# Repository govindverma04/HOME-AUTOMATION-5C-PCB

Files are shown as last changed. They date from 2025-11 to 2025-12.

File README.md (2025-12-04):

# HOME-AUTOMATION-5C-PCB

# Smart Home Automation PCB

This is an open-source ESP32-based smart home automation PCB designed by me.  
It includes zero-cross detection, triac dimming, relay control and support for Alexa/Google integration (optional).

---

## 🚀 Features
- ESP32-based main controller  
- 4N25 Zero-Cross Detection  
- Triac-based AC dimming  
- Relay output for AC load ON/OFF  
- Indicator LEDs  
- Safe opto-isolated design  
- Can be used for fan dimming & bulb control  

---

## 🧰 Files in this Repository
- `schematics/` → Circuit diagram  
- `pcb/` → PCB design files  
- `firmware/` → ESP32 code  
- `bom/` → Part list of components  
- `images/` → PCB photos & renders  

---

## 🔧 How to Use / Instructions

### 1) Assemble the PCB
- Solder all resistors  
- Solder optocouplers (4N25, MOC3021, etc)  
- Solder triac (BT136 or chosen model)  
- Mount terminal blocks  
- Insert ESP32  

### 2) Power Requirements
- 5V input via Hi-Link / External SMPS  
- ESP32 runs at 3.3V (regulator included)

### 3) Upload the Firmware
1. Download code from `firmware/` folder  
2. Open in Arduino IDE or PlatformIO  
3. Select board → ESP32 Dev Module  
4. Upload code  
5. Open Serial Monitor → you should see boot messages  

### 4) Connecting AC Load (⚠️ Safety First!)
- Only connect AC when you are confident  
- Use proper insulation  
- Fan/Bulb should connect through triac output  
- Relay output supports ON/OFF loads  

---

## 🧪 Testing
- Connect a test load or bulb  
- Verify Zero-Cross is detected (LED should blink)  
- Check dimming using serial or app  
- Test safety circuits  

---

## 🤝 Contributing
If you want to improve this project:
- Open an issue  
- Submit a pull request  
- Suggest new features  

---

## 📜 License
This project is open-source under the MIT License.

---

## 📞 Contact
Maintainer: **Govind**  
GitHub: https://github.com/govindverma04

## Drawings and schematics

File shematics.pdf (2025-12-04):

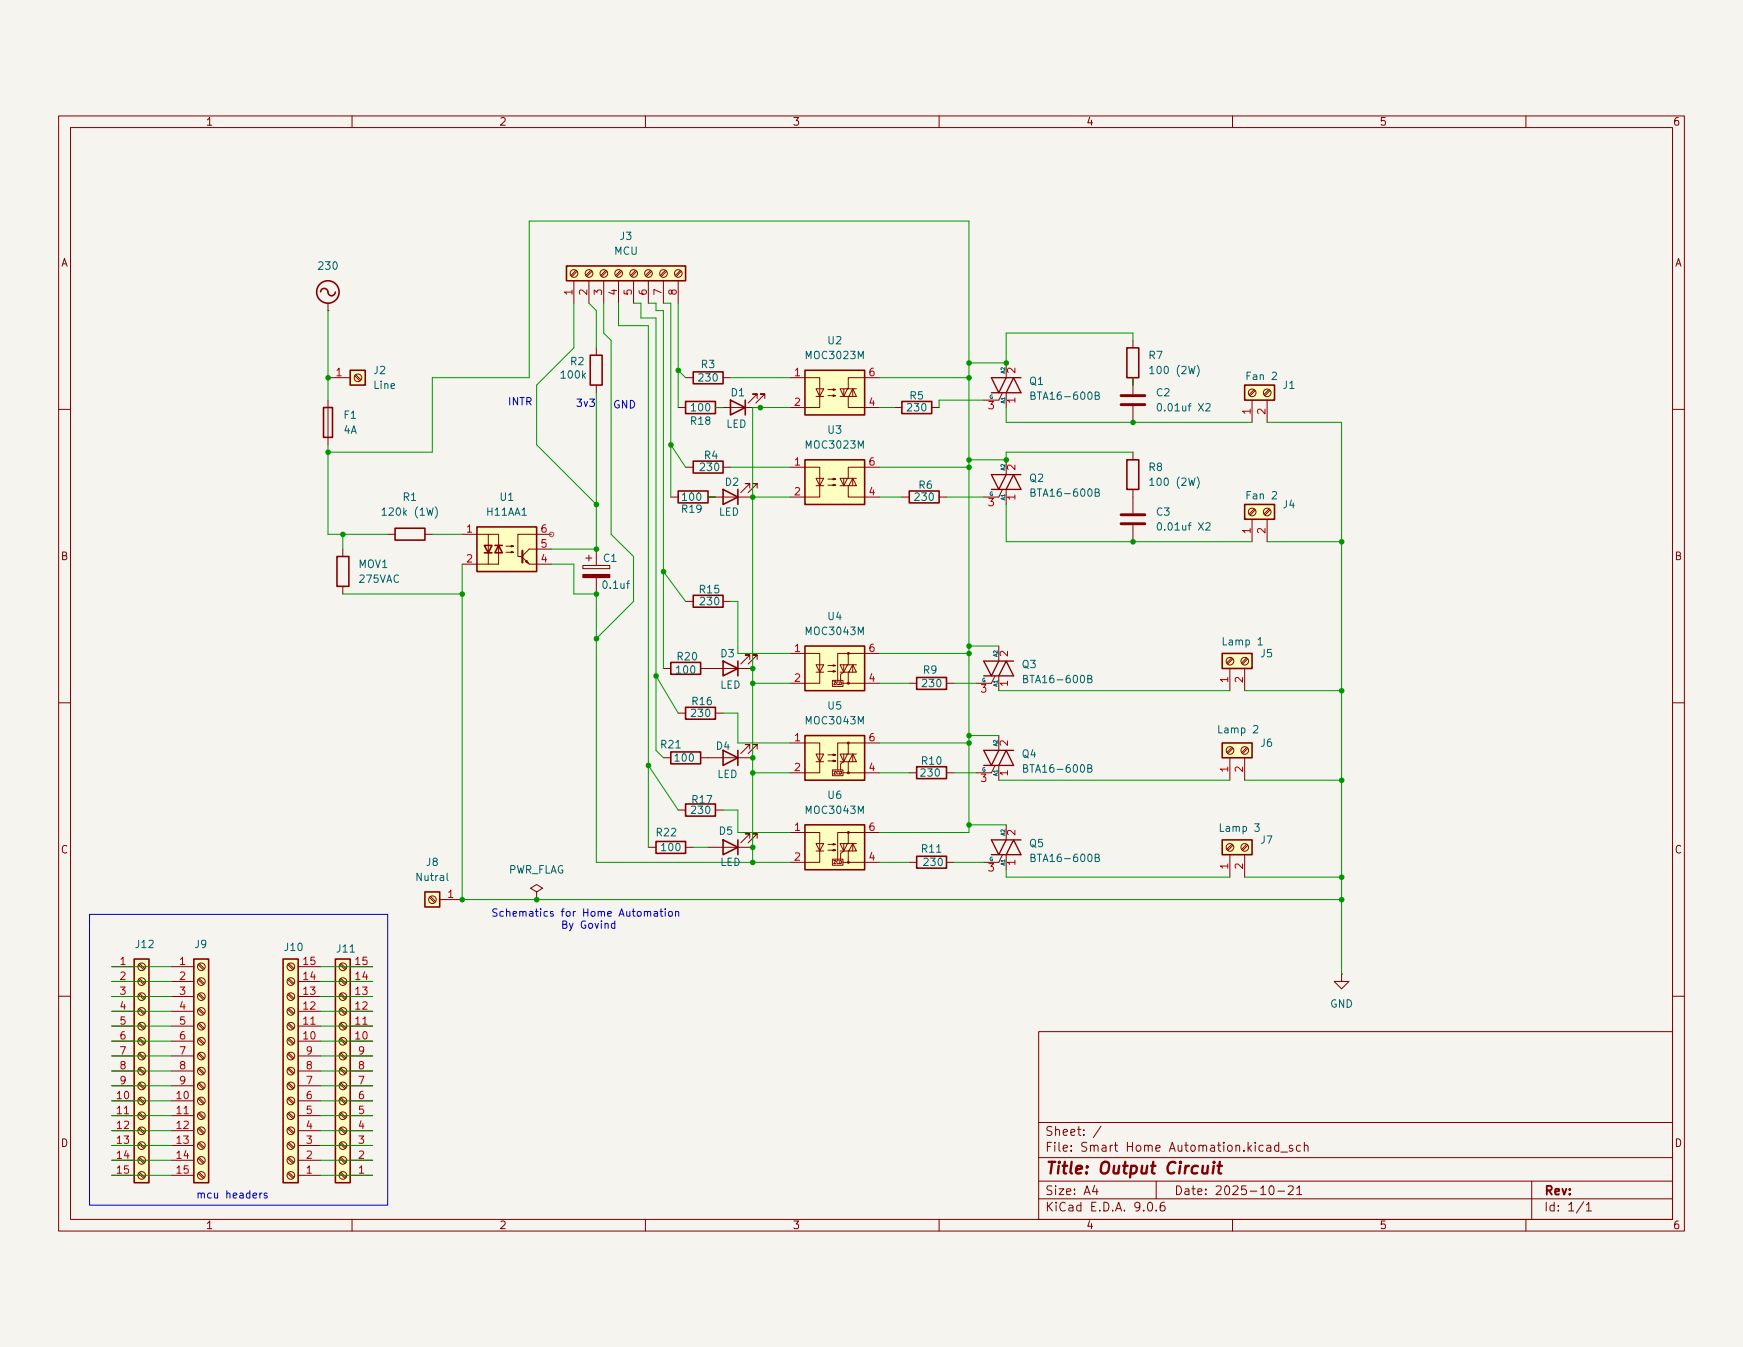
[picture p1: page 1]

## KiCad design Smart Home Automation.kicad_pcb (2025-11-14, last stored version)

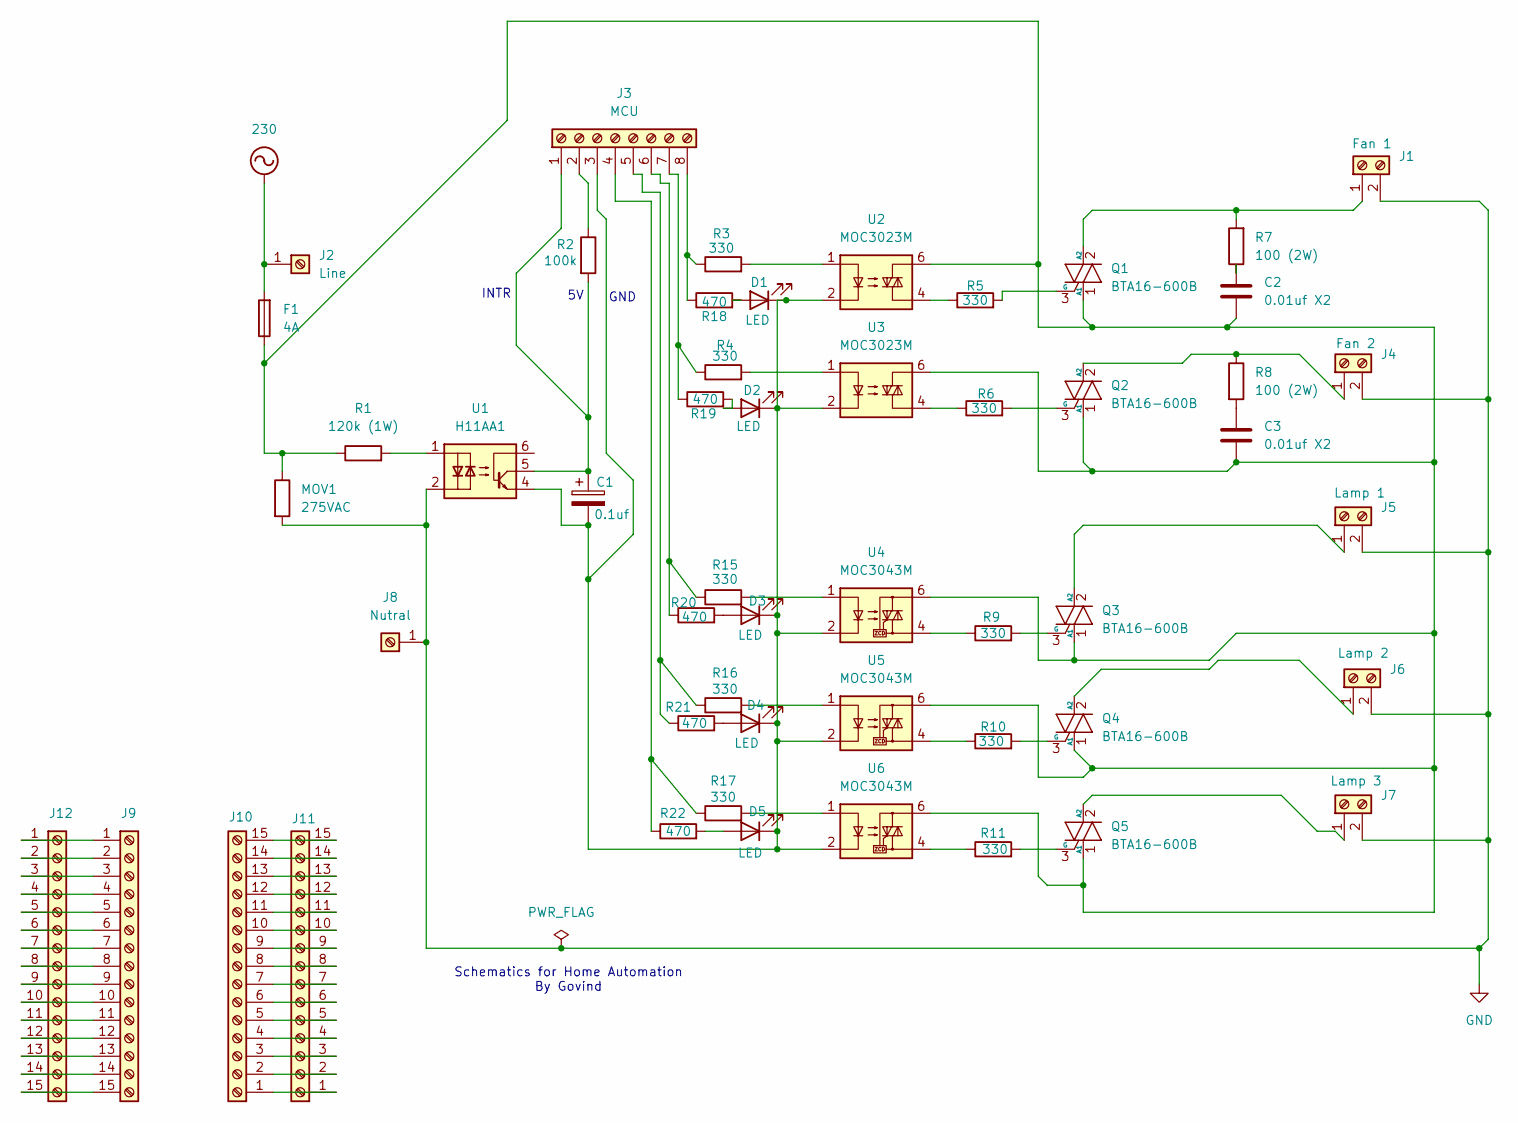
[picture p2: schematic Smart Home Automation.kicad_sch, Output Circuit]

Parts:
C1: 0.1uf; CP_Radial_D5.0mm_P2.00mm
C2, C3: 0.01uf X2; CP_Radial_D5.0mm_P2.00mm
D1, D2, D3, D4, D5: LED; LED_D1.8mm_W3.3mm_H2.4mm
F1: 4A; Fuseholder_Cylinder-5x20mm_Schurter_0031_8201_Horizontal_Op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
J1: Fan 1; PinSocket_1x02_P2.54mm_Vertical
J2: Line; Pin_D0.7mm_L6.5mm_W1.8mm_FlatFork
J3: MCU; PinSocket_1x08_P2.54mm_Vertical
J4: Fan 2; PinSocket_1x02_P2.54mm_Vertical
J5: Lamp 1; PinSocket_1x02_P2.54mm_Vertical
J6: Lamp 2; PinSocket_1x02_P2.54mm_Vertical
J7: Lamp 3; PinSocket_1x02_P2.54mm_Vertical
J8: Nutral; Pin_D0.7mm_L6.5mm_W1.8mm_FlatFork
J9, J10, J11, J12: Screw_Terminal_01x15; PinSocket_1x15_P2.54mm_Vertical
MOV1: 275VAC; RV_Disc_D7mm_W3.4mm_P5mm
Q1, Q2, Q3, Q4, Q5: BTA16-600B; TO-220-3_Vertical
R1: 120k (1W); R_Axial_DIN0204_L3.6mm_D1.6mm_P7.62mm_Horizontal
R2: 100k; R_Axial_DIN0204_L3.6mm_D1.6mm_P5.08mm_Horizontal
R3, R4, R5, R6, R9, R10, R11, R15, R16, R17: 330; R_Axial_DIN0204_L3.6mm_D1.6mm_P5.08mm_Horizontal
R7, R8: 100 (2W); R_Axial_DIN0204_L3.6mm_D1.6mm_P5.08mm_Horizontal
R18, R19, R20, R21, R22: 470; R_Axial_DIN0204_L3.6mm_D1.6mm_P5.08mm_Horizontal
U1: H11AA1; DIP-6_W7.62mm
U2, U3: MOC3023M; DIP-6_W10.16mm
U4, U5, U6: MOC3043M; DIP-6_W10.16mm

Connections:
230: F1.2, J2.1
GND: J1.2, J4.2, J5.2, J6.2, J7.2, J8.1, MOV1.2, U1.2
unnamed: C2.1, R7.1
unnamed: C3.1, R8.2
unnamed: D1.2 (A), R18.2
unnamed: C1.2, D1.1 (K), D2.1 (K), D3.1 (K), D4.1 (K), D5.1 (K), J3.3, U1.4, U2.2, U3.2, U4.2, U5.2, U6.2
unnamed: D2.2 (A), R19.2
unnamed: D3.2 (A), R20.2
unnamed: D4.2 (A), R21.2
unnamed: D5.2 (A), R22.2
unnamed: J1.1, Q1.2 (A2), R7.2
unnamed: C1.1, J3.1, R2.2, U1.5
unnamed: J3.2, R2.1
unnamed: J3.4, R17.1, R22.1
unnamed: J3.5, R16.1, R21.1
unnamed: J3.6, R15.1, R20.1
unnamed: J3.7, R4.1, R19.1
unnamed: J3.8, R3.1, R18.1
unnamed: J4.1, Q2.2 (A2), R8.1
unnamed: J5.1, Q3.2 (A2)
unnamed: J6.1, Q4.2 (A2)
unnamed: J7.1, Q5.2 (A2)
unnamed: J10.1, J11.1
unnamed: J10.2, J11.2
unnamed: J10.3, J11.3
unnamed: J10.4, J11.4
unnamed: J10.5, J11.5
unnamed: J10.6, J11.6
unnamed: J10.7, J11.7
unnamed: J10.8, J11.8
unnamed: J10.9, J11.9
unnamed: J10.10, J11.10
unnamed: J10.11, J11.11
unnamed: J10.12, J11.12
unnamed: J10.13, J11.13
unnamed: J10.14, J11.14
unnamed: J10.15, J11.15
unnamed: J9.1, J12.1
unnamed: J9.2, J12.2
unnamed: J9.3, J12.3
unnamed: J9.4, J12.4
unnamed: J9.5, J12.5
unnamed: J9.6, J12.6
unnamed: J9.7, J12.7
unnamed: J9.8, J12.8
unnamed: J9.9, J12.9
unnamed: J9.10, J12.10
unnamed: J9.11, J12.11
unnamed: J9.12, J12.12
unnamed: J9.13, J12.13
unnamed: J9.14, J12.14
unnamed: J9.15, J12.15
unnamed: C2.2, C3.2, F1.1, MOV1.1, Q1.1 (A1), Q2.1 (A1), Q3.1 (A1), Q4.1 (A1), Q5.1 (A1), R1.1, U2.6, U3.6, U4.6, U5.6, U6.6
unnamed: Q1.3 (G), R5.2
unnamed: Q2.3 (G), R6.2
unnamed: Q3.3 (G), R9.2
unnamed: Q4.3 (G), R10.2
unnamed: Q5.3 (G), R11.2
unnamed: R1.2, U1.1
unnamed: R3.2, U2.1
unnamed: R4.2, U3.1
unnamed: R5.1, U2.4
unnamed: R6.1, U3.4
unnamed: R9.1, U4.4
unnamed: R10.1, U5.4
unnamed: R11.1, U6.4
unnamed: R15.2, U4.1
unnamed: R16.2, U5.1
unnamed: R17.2, U6.1

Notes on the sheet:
Schematics for Home Automation By Govind
INTR
GND

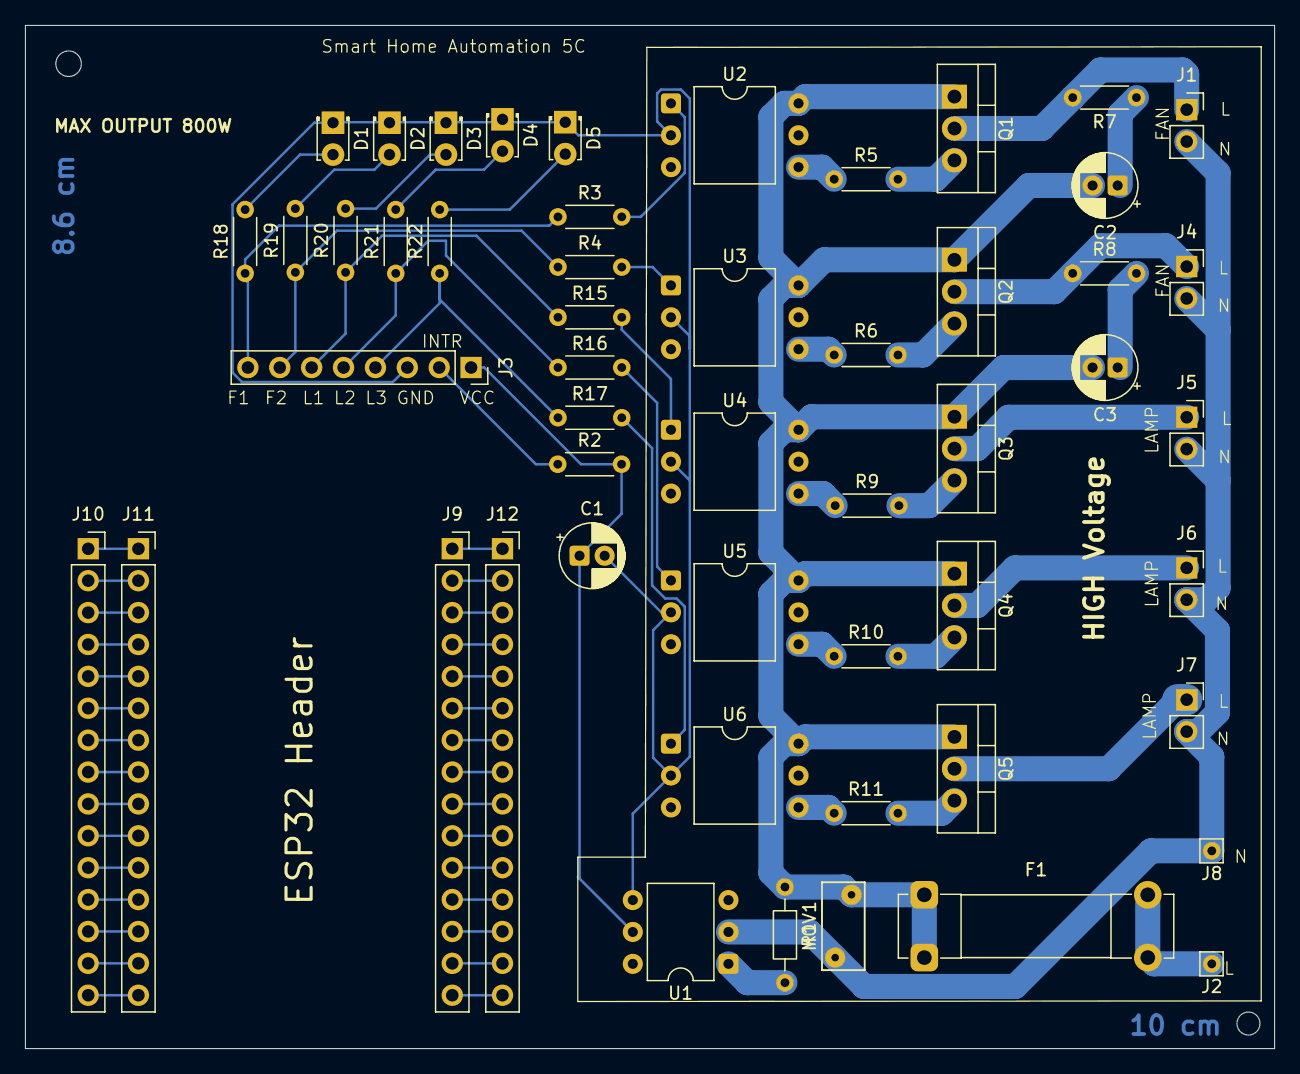
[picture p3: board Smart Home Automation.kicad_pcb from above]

Board: 2 copper layers, 99.5 x 81.5 mm, 52 parts (0 on the bottom side), 69 nets.
